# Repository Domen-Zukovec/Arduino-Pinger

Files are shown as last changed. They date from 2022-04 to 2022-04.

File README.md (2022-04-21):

# Arduino pinger
----------------
## Outside
- four buttons
- Red and green LEDs
- LCD display


## Inside
- shield for soldering
- ethernet shield
- Arduino mega 2560


## Functions
- Ping
- Checking the connection, does it work or not
- Detect whether the cable is connected
- Network detection (internet or voice / video)

## Pinging
- Local
- Google
- Voice
- Video


## One time ping
- OK


- ERROR



## Ping till cancel
- OK


- ERROR



## Circuits


## Extra info
- The program has 2002 lines of code in the C ++ programming language
- In addition to the loop and setup, there are 9 other functions
- It has 105 if conditions
- We use the while loop 38 times

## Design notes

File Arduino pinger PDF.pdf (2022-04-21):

# Arduino pinger

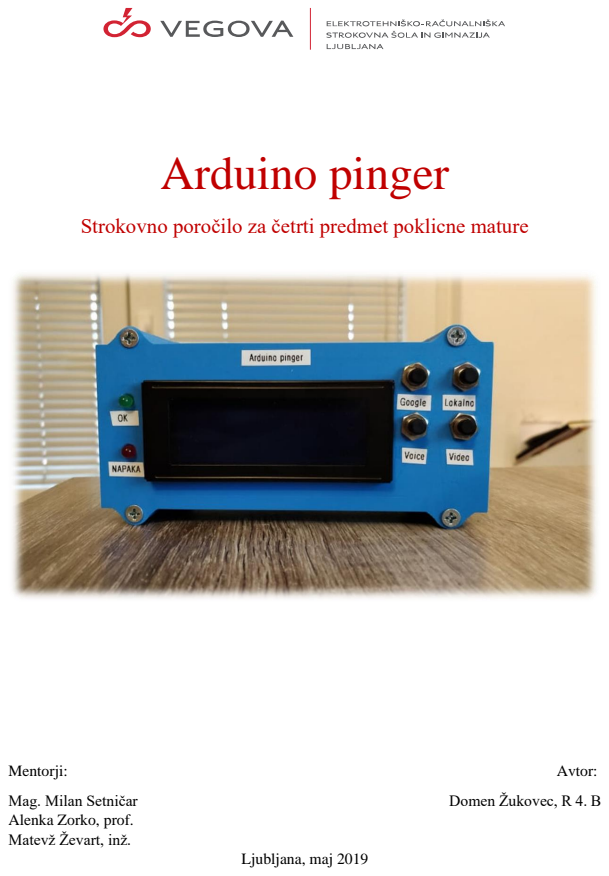
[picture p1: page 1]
Mentorji:; Avtor:; Mag. Milan Setničar; Domen Žukovec, R 4. B; Ljubljana, maj 2019

Strokovno poročilo za četrti predmet poklicne mature

Alenka Zorko, prof.
Matevž Ževart, inž.

### Povzetek

V poročilu je predstavljen tester omrežij Arduino pinger. Na začetku so opisana računalniška omrežja, natančneje osebna in javna. Nato pa so predstavljena orodja in okolja, ki sem jih uporabljal za izdelavo testerja. Sledi podrobna predstavitev delovanja in sestave Arduino pingerja, za tem pa še težave, s katerimi sem se soočil pri izdelavi.

Ključne besede: Arduino, Arduino pinger, usmerjevalnik, testiranje omrežja

### Abstract

In this report a network tester named is presented. First, we talk about computer networks, specifically public and home networks. Then tools and environments that I used for the creation of the tester are introduced. That follows with a detailed presentation on how the Arduino pinger works and how it's made. Next we talk about some problems I had to work around and in the end I present a conclusion.

Key words: Arduino, Arduino pinger, router, network testing

## Kazalo

## Kazalo slik

# 1.Uvod

Za izdelavo Arduino pingerja sem se odločil, saj za testiranje omrežja z računalnikom tehnik na terenu porabi preveč časa in usmerjevalnik brez kakršnegakoli testiranja velikokrat kar zamenja za novega. Delujoči usmerjevalniki so zato velikokrat brez potrebe poslani na servis, kar podjetjem, sploh večjim kot so Telekom d. d., povzroča velike denarne izgube. Spodbudo za izdelavo naprave mi je dal mentor Matevž Ževart med prakso na Telekomu. Arduino pinger je kompaktna in lahka naprava, ki jo tehnik lahko brez težav nosi po terenu in z njo v sekundah preveri delovanje povezave z usmerjevalnikom, glavnim strežnikom Googla (torej internetom) in s telefonsko ter televizijsko linijo (1).

# 2. Računalniška omrežja

## 2.1 Domače omrežje

Je proces povezovanja vseh naprav v domu skupaj z internetom. Domače omrežje se uporablja za vzpostavitev povezave med napravami, ki jih uporabljamo doma. Podobno je standardnemu omrežju LAN ali WLAN, ki je krajevno omejeno. Predvsem ga uporabljamo za povezovanje potrošnikov in njihovih naprav. Ti vključujejo računalnike, prenosnike, mobilne telefone, tablice in televizorje. Na splošno se domače omrežje lahko doseže s pomočjo usmerjevalnika, ki ga nudi ponudnik internetnih storitev, ki ima lahko podporo za več žičnih ali brezžičnih vrst povezav. Vse naprave se lahko neposredno povežejo z modemom, da lahko dostopajo do interneta (2).

## 2.2 Javno omrežje

Je vrsta omrežja do katerega ima lahko dostop vsakdo in se prek njega lahko poveže z drugimi omrežji ali internetom. To je v nasprotju z zasebnim (domačim) omrežjem, kjer se določijo omejitve in pravila dostopa. Ker ima javno omrežje malo omejitev ali pa jih sploh nima, morajo uporabniki pri dostopanji paziti na morebitna varnostna tveganja. Javno omrežje je označba uporabe in ne topologija ali drugo tehnično povezano načelo. Tehnične razlike med zasebnim in javnim omrežjem glede strojno opremo in infrastrukturo ni, razen varnostnih sistemov ter sistemov za nastavljanje in preverjanje prisotnosti (3).

# 3. Orodja in okolja

## 3.1 Arduino

Arduino je podjetje, ki temelji na odprtokodni strojni in programski opremi. Poleg podjetja je tudi skupnost, kateri lahko prispeva vsak. Glavna funkcija podjetja je oblikovanje in izdelovanje enoploščnih mikrokrmilnikov ter mikrokrmilniških kompletov za izgradnjo digitalnih naprav in interaktivnih objektov. Njihovi izdelki so licencirani v skladu z GNU General Public License (GPL) oziroma z splošno javno licenco, kar omogoča izdelavo Arduino plošč in distribucijo programske opreme z strani vseh. Vezja so komercialno na voljo v že vnaprej sestavljeni obliki ali pa kot kompleti za samo izdelavo.

Modeli plošč uporabljajo vrsto mikroprocesorjev in krmilnikov. Vezja so opremljena z digitalnimi in analognimi vhodi ali izhodi, na katere lahko priklopimo različne razširitvene plošče (ščite) ali pa druga vezja. Nekateri modeli imajo serijske komunikacijske vmesnike, vključno z univerzalnim serijskim vodilom (USB), ki se uporablja tuti za nalaganje programov iz osebnih računalnikov. Mikrokontrolerje običajno sprogramiramo z pomočjo funkcij iz programskih jezikov C in C++. Poleg tradicionalnih orodij za programiranje, projekt Arduino zagotavlja svoje integrirano razvojno okolje (IDE) (4).

## 3.1.1 Zgodovina

Projekt Arduino se je začel leta 2003 kot program za študente na Interactive Design Institute Ivrea v Italiji, s ciljem začetnikom in strokovnjakom zagotoviti poceni in preprost način za ustvarjanje naprav. Primeri takšnih naprav, namenjenih začetnikom, so enostavni roboti, termostati in detektorji gibanja. Ime Arduino izhaja iz bara v Ivrea v Italiji, kjer so se srečali ustanovitelji projekta.

## 3.1.2 Arduino Mega 2560

Mega 2560 je zasnovan za bolj komplekse projekte. Ima 54 digitalnih vhodno/izhodnih zatičev (od tega 15 lahko uporabimo kot PWM-izhode), 16 analognih vhodov, 4 UART(strojna serijska vrata), 16 MHz-kristalni oscilator, USB-povezljivost, vtičnico, ICSP-glavo in gumb za ponastavitev. Vsebuje vse, kar je potrebno za podporo mikrokrmilnika. Plošča Mega 2560 je združljiva z večino ščitov za Uno.

## 3.1.3 Arduinovo integrirano razvojno okolje (IDE)

Je aplikacija za Windows, MacOS, Linux, ki je napisana v programskem jeziku Java. Izvira iz integriranega razvojnega okolja za programska jezika Processing in Wiring. Vključuje urejevalnik kod s funkcijami, kot so izrezovanje in lepljenje besedila, iskanje in zamenjava besedila, samodejno zamikanje, ujemanje spojev, avtomatsko urejanje kode in poudarjanje sintaks. Omogoča prevajanje in nalaganje skripte na Arduino vezje z enim klikom. Vsebuje tudi območje za sporočila, besedilno konzolo, orodno vrstico gumbi za skupne funkcije in hierarhijo menijev.

Arduino IDE podpira jetike C in C++ s posebnimi pravili strukturiranja kode. Programsko knjižnico dobavlja iz projekta Wiring, ki ponuja številčne skupne vhodne in izhodne postopke. Uporabniško napisana koda zahteva samo dve osnovni funkciji, za zagon skice in glavne programske zanke, ki sta main() in loop(). Arduino IDE uporablja program Avrdude za pretvorbo izvršljive kode v besedilno datoteko v šestnajstiškem kodiranju, ki se naloži na Arduino ploščo s programom za nalaganje.

3.2 C++

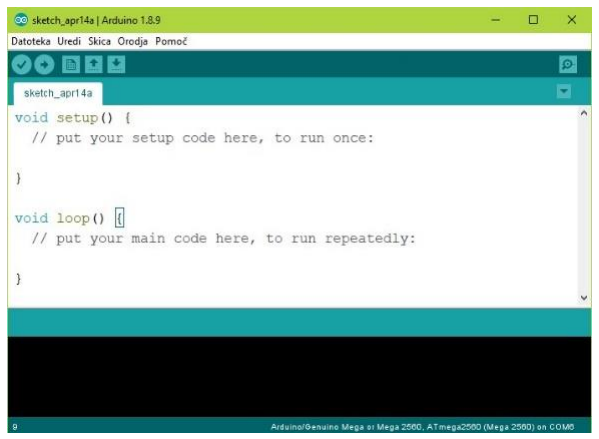
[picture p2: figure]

Programski jezik C++ je izboljšana verzija jezika C, ki se običajno uporablja za objektno usmerjeno programiranje. Razvija se že več kot trideset let. Čeprav je to daleč od najstarejšega računalniškega jezika, je to eden starejših, ki je danes v splošni rabi. Zato lahko rečemo da je dobil petko ta sposobnost prilagajanja spreminjajočim se tehnološkim časom.

C++ je razvil Bjarne Strostrup, ki je opravil prvi prototip kot del svojega doktorskega projekta. V zgodnjih letih se je imenoval jezik »C z razredi«. Začel je razvijati nov jezik, ker je menil, da noben obstoječ ni bil idealen za velike projekte. Kasneje, ko je delal v AT&T Bell Labs, se je spet počutil omejeno. Zavrgel je svoj »C z razredi« in upeljal še druge jezike. Na koncu je poleg razredov dodal še virtualne funkcije, predloge (templates) in preobremenitev operatorja (operator overloading).

Slika 1: Arduinovo IDE-okolje

C++ je precej presegel delo enega človeka. Ime se je dejansko spomnil drug razvijalec Rick Mascitti. Delno je bila igra besed na ime operaterja »++« in delno sklicevanje na izboljšavo (dva plusa sta morda tudi šala).

Jezik je bil prvič standardiziran leta 1998. Standardi si bili ponovno obnovljeni leta 2003, 2007 in 2011. Jezik C++ zdaj vzdržuje International Organization for Standardization (ISO), ki je velika organizacija za standarde. Trenutna različica programskega jezika je C++20. Glavni cilji za zdaj so, da postane boljši jezik za vgrajene sisteme in da bolje podpira novince.

C++ se pogosto uporablja v programskem inženirstvu vgrajenih sistemov. Priljubljen je tudi v komunikacijskih aplikacijah in igrah. Uporablja se v mnogih različnih panogah, kot so zdravstvo, finance…Eden od razlogov, da se programerji odločijo za C++, je, da se dobro povezuje z drugimi programskimi jeziki. Še en plus je njegova visoka zmogljivost. C++ je vplival tudi na kasnejše jezike, kot so PHP, Java, C#... (5)

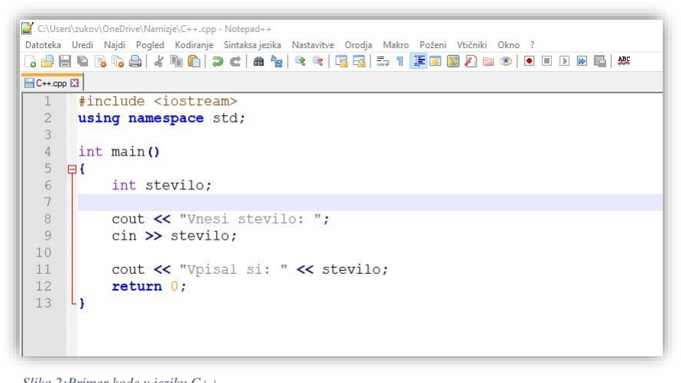
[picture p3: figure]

## 3.3Notepad++

Notepad++ je brezplačen urejevalnik izvorne kode in nadomestek za beležnico, ki podpira veliko več programskih jezikov. Temelji na zmogljivi komponenti za urejanje Scintilla, napisan je v jeziku C++ in uporablja Win32 API in STL, ki zagotavlja višjo hitrost izvajanja in manjšo velikost programa. Z dobro optimizacijo poskuša Notepad++ uporabniku ponuditi najboljšo možno storitev z minimalno procesorsko močjo (6).

Slika 2:Primer kode v jeziku C++

## 3.4 3D-tiskanje

## 3.4.1 Delovanje 3D-tiskanja

Vsak 3D-tiskalnik deluje na isti glavni princip. Digitalni model se spremeni v fizični tridimenzionalni objekt z dodajanjem materiala (plastike) plast na plast. 3D-tiskanje je bistveno drugačen način izdelave delov v primerjavi s tradicionalnimi tehnologijami izrezovanja (CNC obdelava) ali proizvodnimi tehnologijami (injection molding). Pri 3D tiskanju niso potrebna posebna orodja (npr. rezalno orodje z določeno geometrijo ali kalup). Namesto tega je izdelan neposredno na vgrajeno platformo, po slojih, kar vodi do edinstvenih nizov prednosti in omejitev.

Proces se vedno začne z digitalnim 3D-modelom (načrtom fizičnega objekta). Model s programsko opremo tiskalnika razdelimo v tanke, dvodimenzionalne plasti, ki jih nato pretvori v niz navodil, da jih lahko tiskalnik tiska.

3D-tiskanje se lahko razlikuje odvisno od procesa, s katerim tiskamo. Na primer, namizni računalniki raztapljajo plastične filamente in jih položijo na tiskalno platformo skozi šobo. Veliki industrijski SLS stroji pa uporabljajo laser za taljenje (ali sintranje) tankih plasti kovinskih ali plastičnih prahov. Razpoložljivi materiali se razlikujejo tudi glede na proces. Plastika je daleč najpogostejša, uporabljamo pa lahko tudi kovino. Proizvedeni deli imajo lahko tudi širok spekter specifičnih lastnosti, od optično čistih, do gumastih predmetov. Odvisno od velikosti dela in vrste tiskalnika lahko traja tiskanje od štiri do osemnajst ur. Tiskani deli pa so redko pripravljeni za uporabo takoj po tisku. Velikokrat zahtevajo še nekaj naknadne obdelave, da se doseže želena raven kvalitete. Ti koraki zahtevajo dodaten čas in običajno ročen napor (7).

## 3.4.2 Zgodovina 3D-tiskalnikov

Arthur C. Clarke je prvič opisal osnovne funkcije 3D-tiskalnika leta 1964. Prvi 3D tiskalnik je leta 1987 izdelal Chuck Hull, uporabljal pa je sistem »stereolitografije«. V devetdesetih in dva tisočih so bile izdelane druge tehnologije 3D-tiskanja (FDM in SLS). Ti tiskalniki so bili dragi in se v glavnem uporabljajo za industrijsko izdelavo prototipov. Odbor za ASTM F42 je leta 2009 objavil dokument s standardno terminologijo o aditivni proizvodnji. To je vzpostavilo 3D tiskanje kot industrijsko proizvodnjo tehnologijo. V istem letu so se patenti za FDM iztekli in prvi poceni 3D namizni tiskalniki so začeli nastajati pod okvirjem projekta RepRap. Kar je nekoč stalo 200.000€, je nenadoma postalo dostopno za manj kot 2.000€. V obdobju 2015-2017 je bilo globalno prodanih več kot 1 milijon 3D-tiskalnikov, prodaja industrijskih kovinskih tiskalnikov pa se je leta 2017 v primerjavi s prejšnjim letom skoraj podvojila.

## 3.4.3 Tinkercad

Ustanovljen je bil leta 2011. Je največja skupnost 3D-oblikovalcev in navdušencev 3D-tiskanja. Do zdaj je privabil več kot sedem milijonov uporabnikov, vsako minuto pa se pridružijo novi. Aktivna skupnost je skupaj ustvarila že več kot petdeset milijonov 3D modelov, vsak dan pa je dodanih še na tisoče novih. Konec leta 2016 je prvotni Tinkercad urednik predstavil popolnoma prenovljen urejevalnik v2.0, ki deluje 800 % hitreje kot prej in nam omogoča, da povečavo aplikacije na načine, ki jih stari ne more. Junija 2013 je Tinkercad postal del družine aplikacij Autodeska (8).

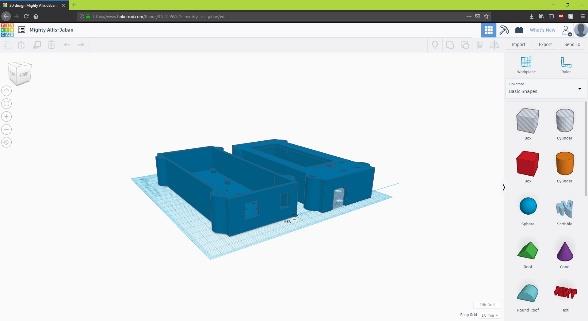
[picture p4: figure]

# 4. Delovanje

## 4.1 Program in funkcije

Program je napisan v Arduinovem IDE-okolju. Glavne funkcije so enkraten ali konstanten ping lokalnega usmerjevalnika, Googlovega strežnika, telefonske ali video mreže Telekoma Slovenije. Rezultat se izpiše na LCD-zaslonu, za hitrejše razumevanje pa besedilo na zaslonu podpirata se ustrezno prižgani rdeča ali zelena dioda.

Slika 3: Ohišje Arduino pingerja v programu Tinkercad

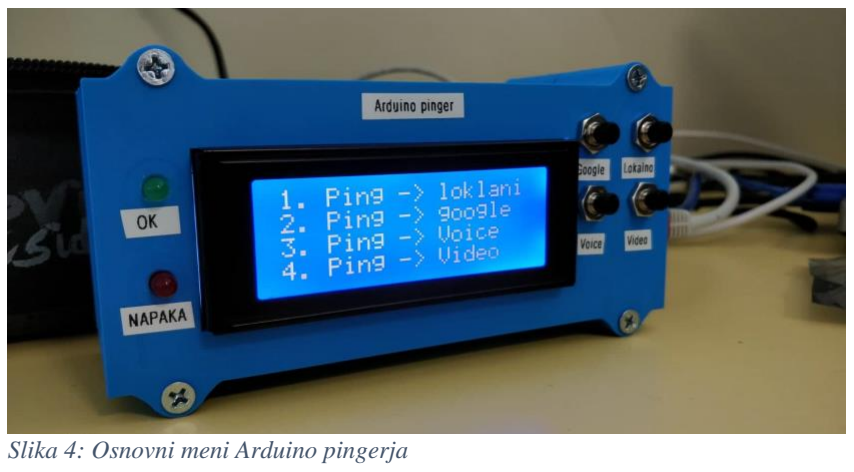
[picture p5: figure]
Slika 4: Osnovni meni Arduino pingerja

## 4.1.1 Osnovne deklaracije

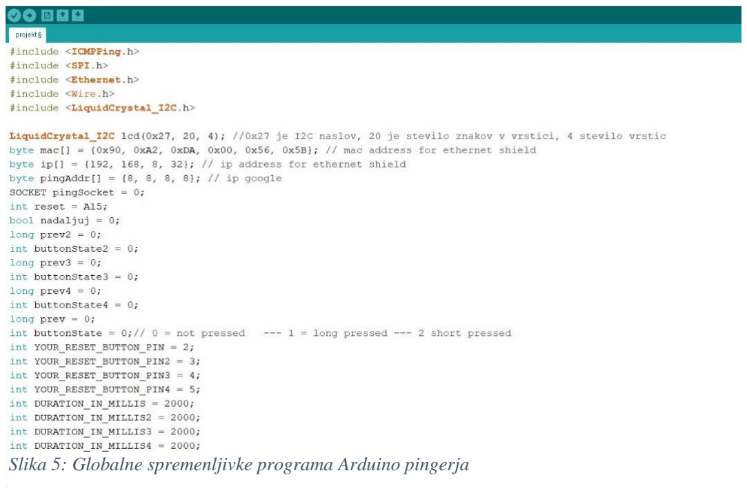
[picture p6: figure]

Izven vseh funkcij se deklarirajo globalne spremenljivke, ki se bodo uporabljale v več kot eni funkciji. Z #include pa se navežemo na knjižnice, ki jih Arduinov IDE v osnovi še nima vključenih. Navezati sem se moral na knjižnice za delovanje internetnega ščita in LCD-zaslona.

## 4.1.2 Funkcija rebootEthShield

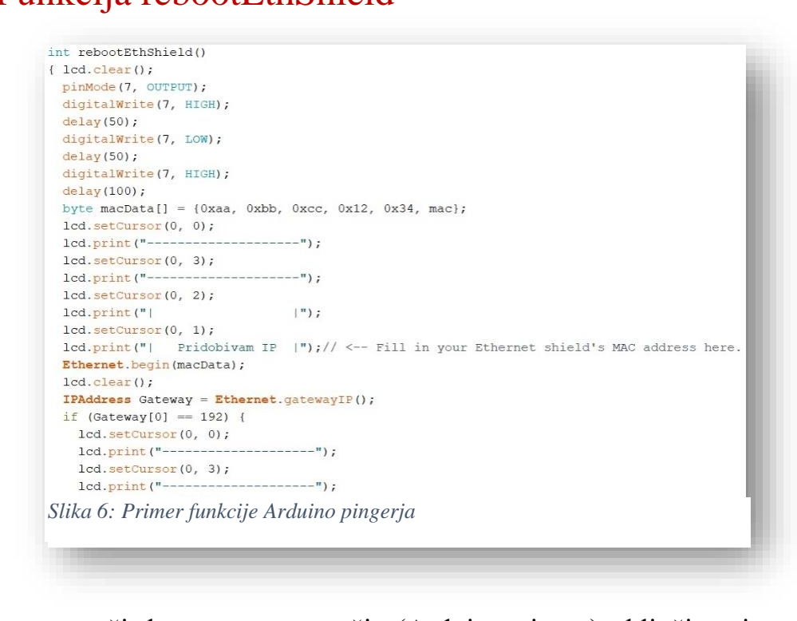
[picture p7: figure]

Funkcija se sproži, ko v tester omrežja (Arduino pinger) vključimo internetni kabel. V funkciji resetiramo internetni ščit (ethernet shield), da dobi nov logični naslov (IP) s katerim bo lahko dostopal na internet oziroma glasovni ali pa video strežnik Telekoma Slovenije.

Slika 5: Globalne spremenljivke programa Arduino pingerja

Slika 6: Primer funkcije Arduino pingerja

## 4.1.3 Funkcije googleKratek

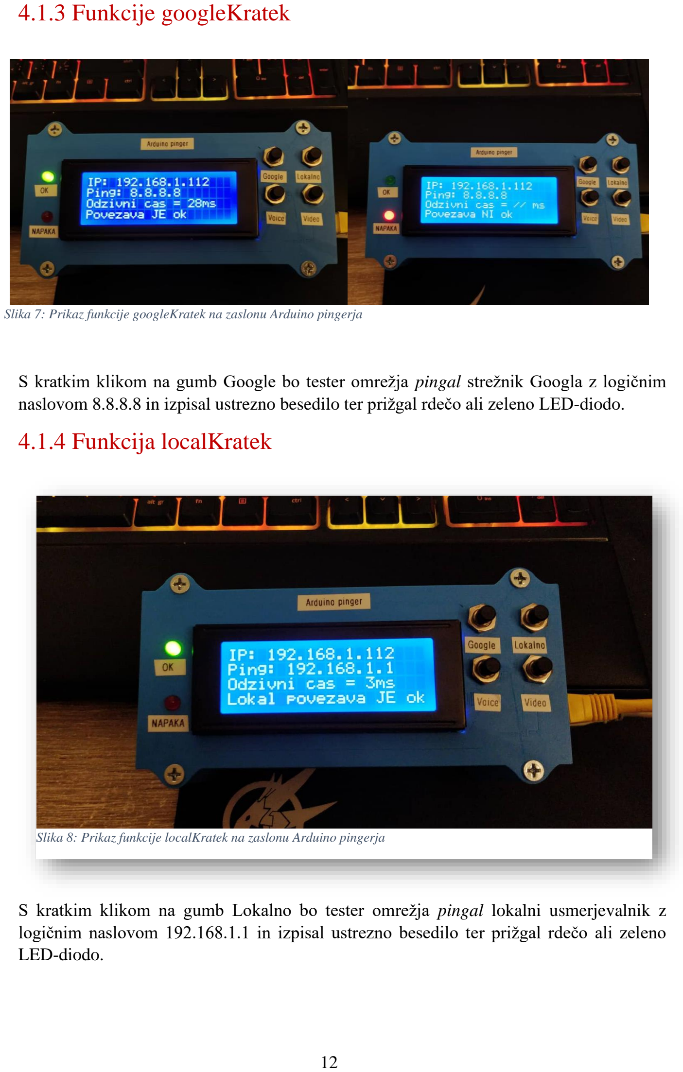
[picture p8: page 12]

S kratkim klikom na gumb Google bo tester omrežja pingal strežnik Googla z logičnim naslovom 8.8.8.8 in izpisal ustrezno besedilo ter prižgal rdečo ali zeleno LED-diodo.

## 4.1.4 Funkcija localKratek

S kratkim klikom na gumb Lokalno bo tester omrežja pingal lokalni usmerjevalnik z logičnim naslovom 192.168.1.1 in izpisal ustrezno besedilo ter prižgal rdečo ali zeleno LED-diodo.

Slika 7: Prikaz funkcije googleKratek na zaslonu Arduino pingerja

Slika 8: Prikaz funkcije localKratek na zaslonu Arduino pingerja

## 4.1.5 Funkcija videoKratek

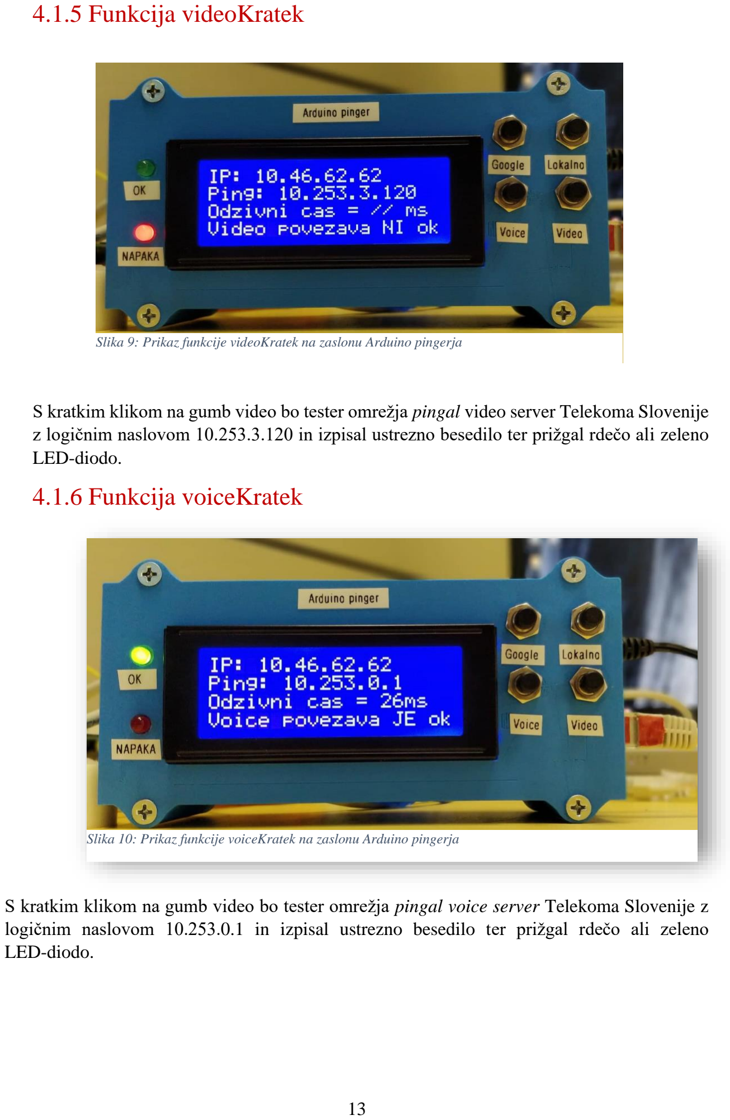
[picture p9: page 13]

S kratkim klikom na gumb video bo tester omrežja pingal video server Telekoma Slovenije z logičnim naslovom 10.253.3.120 in izpisal ustrezno besedilo ter prižgal rdečo ali zeleno LED-diodo.

## 4.1.6 Funkcija voiceKratek

S kratkim klikom na gumb video bo tester omrežja pingal voice server Telekoma Slovenije z logičnim naslovom 10.253.0.1 in izpisal ustrezno besedilo ter prižgal rdečo ali zeleno LED-diodo.

Slika 9: Prikaz funkcije videoKratek na zaslonu Arduino pingerja

Slika 10: Prikaz funkcije voiceKratek na zaslonu Arduino pingerja

## 4.1.7 Funkcija googleDolgi

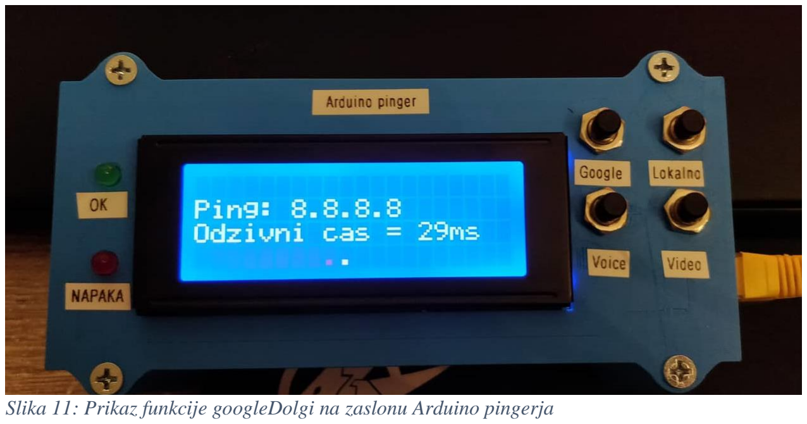
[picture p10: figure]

Z dolgim pritiskom na gumb Google (vsaj dve sekundi) bo tester omrežja začel konstantno pingati strežnik Googla z logičnim naslovom 8.8.8.8, dokler gumba spet ne pridržimo za vsaj dve sekundi. Med pinganjem izpisuje IP, ki ga pingamo, odzivni čas ter indikator s pomočjo katerega lahko izvemo, da pinganje še poteka. V primeru napake v povezavi na LCD-zaslon izpiše »…Ping neuspesen…«

## 4.1.8 Funkcija localDolgi

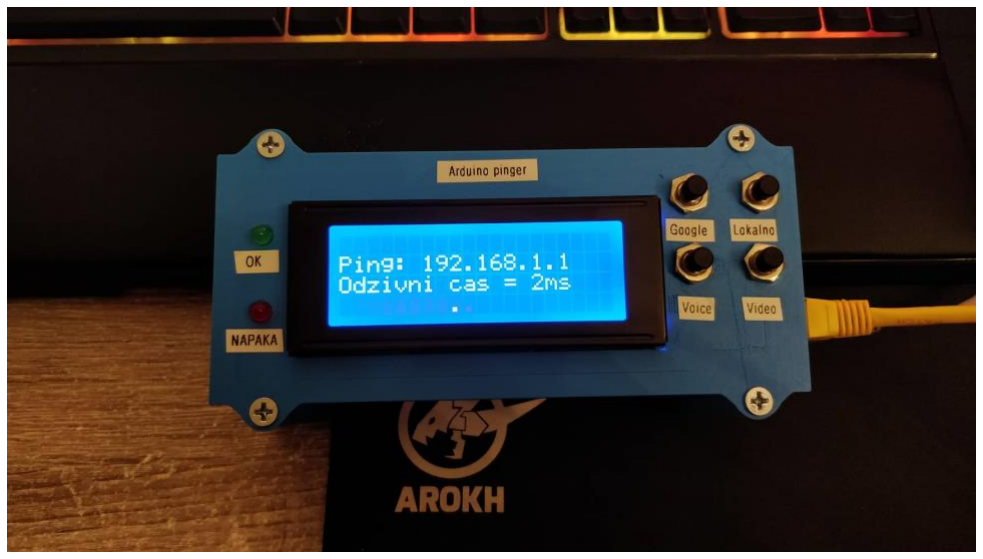
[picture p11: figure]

Z dolgim pritiskom na gumb Lokalno (vsaj dve sekundi) bo tester omrežja začel konstantno pingati lokalni usmerjevalnik z logičnim naslovom 192.167.1.1, dokler gumba spet ne pridržimo za vsaj dve sekundi. Med pinganjem izpisuje IP, ki ga pingamo, odzivni čas ter indikator s pomočjo katerega lahko izvemo, da pinganje še poteka. V primeru napake v povezavi na LCD-zaslon izpiše »…Ping neuspesen…«

Slika 11: Prikaz funkcije googleDolgi na zaslonu Arduino pingerja

Slika 12: Prikaz funkcije localDolgi na zaslonu Arduino pingerja

## 4.1.9 Funkcija videoDolg

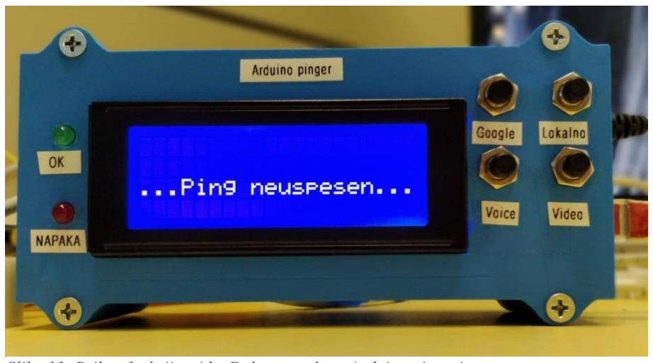
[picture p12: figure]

Z dolgim pritiskom na gumb Video (vsaj dve sekundi) bo tester omrežja začel konstantno pingati video strežnik Telekoma Slovenije z logičnim naslovom 10.253.3.120, dokler gumba spet ne pridržimo za vsaj dve sekundi. Med pinganjem izpisuje IP, ki ga pingamo, odzivni čas ter indikator s pomočjo katerega lahko izvemo, da pinganje še poteka. V primeru napake v povezavi na LCD-zaslon izpiše »…Ping neuspesen…«

## 4.1.10 Funkcija voiceDolg

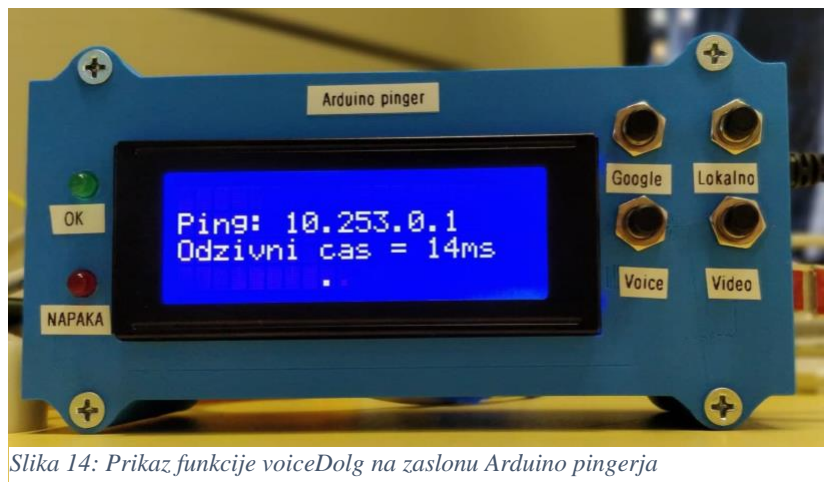
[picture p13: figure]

Z dolgim pritiskom na gumb Video (vsaj dve sekundi) bo tester omrežja začel konstantno pingati voice strežnik Telekoma Slovenije z logičnim naslovom 10.253.0.1, dokler gumba spet ne pridržimo za vsaj dve sekundi. Med pinganjem izpisuje IP, ki ga pingamo, odzivni čas ter indikator s pomočjo katerega lahko izvemo, da pinganje še poteka. V primeru napake v povezavi na LCD-zaslon izpiše »…Ping neuspesen…«

Slika 13: Prikaz funkcije videoDolg na zaslonu Arduino pingerja

Slika 14: Prikaz funkcije voiceDolg na zaslonu Arduino pingerja

## 4.1.11 Funkciji loop in setup

V funkciji loop čakamo na klik gumba in posredno kličemo ustrezno funkcijo. V setupu pa deklariramo spremenljivke in kličemo vse kar potrebujemo za delovanje ostalih funkcij.

## 4.1.12 Preverjanje funkcij gumba

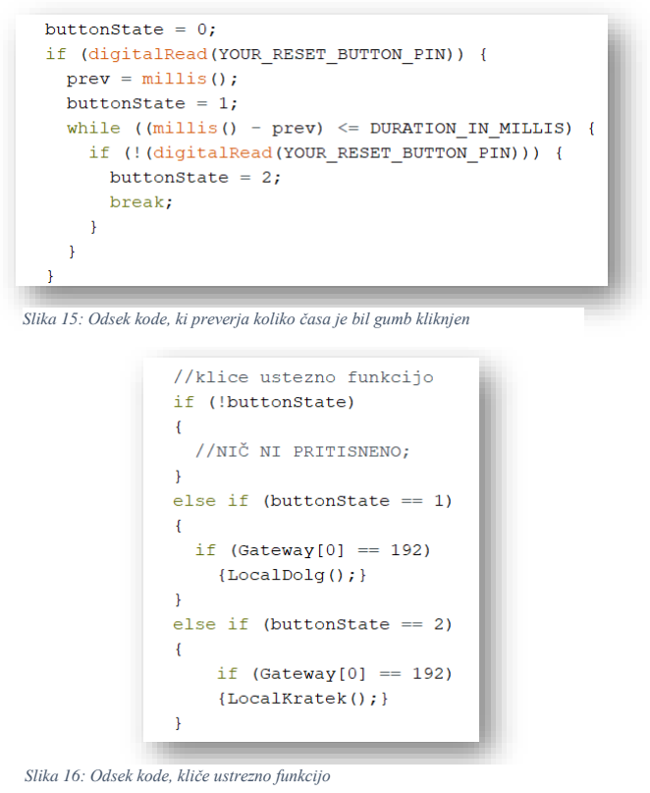
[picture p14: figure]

Na prvi sliki je prikazana koda, s pomočjo katere preverjamo, koliko časa je določen gumb pridržan. To dosežemo z uporabo funkcije millis(). Na drugi sliki pa lahko vidimo, kako se po izvedbi kode iz prve slike izvede if-stavek s katerim se kliče ustrezna funkcija.

Slika 16: Odsek kode, kliče ustrezno funkcijo

Slika 15: Odsek kode, ki preverja koliko časa je bil gumb kliknjen

## 4.2 Sestavni deli

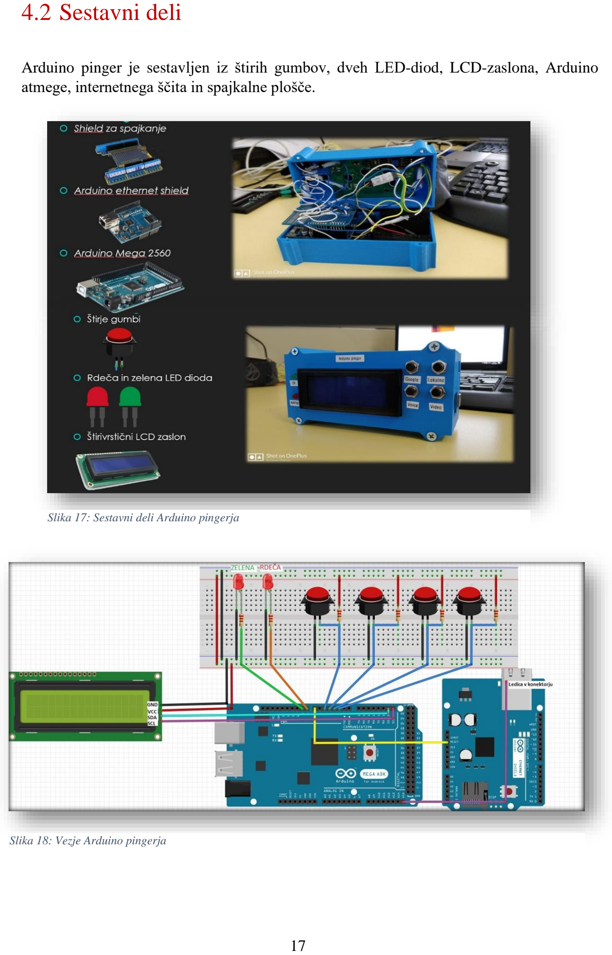
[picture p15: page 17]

Arduino pinger je sestavljen iz štirih gumbov, dveh LED-diod, LCD-zaslona, Arduino atmege, internetnega ščita in spajkalne plošče.

Slika 17: Sestavni deli Arduino pingerja

Slika 18: Vezje Arduino pingerja

# 5.Težave pri razvoju

Pri razvoju sem naletel na le nekaj večjih težav. Prva od teh je bila, da sem imel starejšo različico internetnega ščita, ki ni podpirala ponastavitve preko programske kode, kar pomeni, da sem moral nogico za resetiranje zakriviti, tako da se ni usedla na Arduino, ampak je bila prosta. Nato sem nanjo spajkal kabel, kisem ga vključil v prost vtič Arduinota. Če bi nogico pustil na prvotnem mestu, bi se namreč ščit ponastavil samo skupaj z Arduinom, tako pa sem imel popolno kontrolo nad ponastavitvijo. Drugo večjo težavo pa so mi povzročali gumbi, saj nisem imel dovolj znanja, da bi z enim gumbom zagotovil izvajanje dveh funkcij. S težavo sem se spopadal en teden, preden sem dobil zadovoljivo rešitev. Med izdelavo sem naletel še na obilico majhnih težav, ki sem jih skupaj z mentorjem hitro odpravil.

# 6. Zaključek

Kljub možnostim izboljšave sem z Arduino pingerjem zadovoljen. Lahko bi dodal še številčnico za poljubno vpisovanje logičnih naslovov, a bi bila taka naprava mogoče za nekatere preveč zapletena za uporabo. Namen projekta je bil, da sestavim tester omrežij, ki je preprost za uporabo, a vseeno dovolj zmogljiv, da lahko tehnikom na terenu pomaga pri iskanju napak ali rešitev. Poskušal sem ga narediti čimbolj uporabniku prijaznega in zdi se mi, da mi je to tudi uspelo. Nima odvečnih animacij, uporaba je preprosta in prikaz je lahko razumljiv. V prihodnosti bi rad dodal še notranjo baterijo in izboljšal ohišje oziroma ga poskušal narediti tanjšega.

# 7. Viri in literatura

Vsi internetni viri so bili dosegljivi aprila 2019.

(1) http://wiki.fmf.uni-lj.si/wiki/Vrste_omre%C5%BEja
(2) https://www.techopedia.com/definition/23525/home-networking
(3) https://www.techopedia.com/definition/26424/public-network
(4) https://www.arduino.cc/
(5) https://www.softwareengineerinsider.com/programming-languages/cplusplus.htm
(6) https://notepad-plus-plus.org/
(7) https://www.3dhubs.com/guides/3d-printing/#basics
(8) https://www.tinkercad.com/about/

## 7.1 Viri slik

- Slika na naslovnici: lastna slika, zajeta aprila 2019
- Slike 1–16: lastne slike, zajete aprila 2019

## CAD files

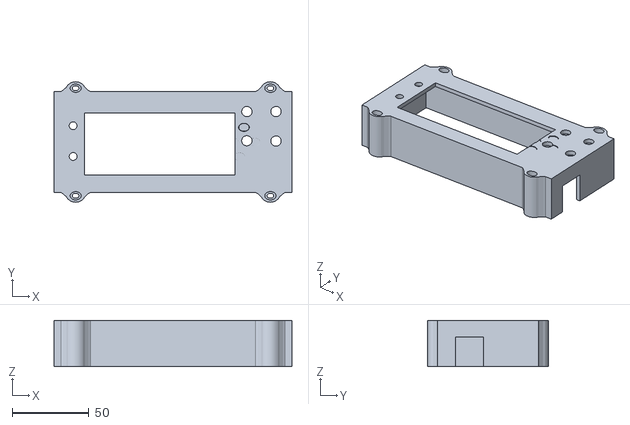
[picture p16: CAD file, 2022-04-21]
Arduino pinger projet/Pinger tinkercad 3D print/Arduino pinger zgornji del popravljen.obj
155.0 x 78.5 x 30.0

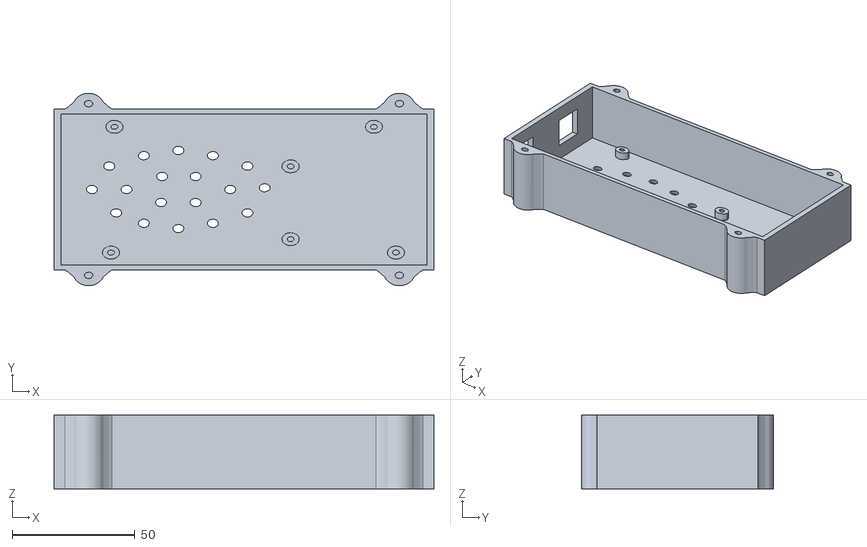
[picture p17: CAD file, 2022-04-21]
Arduino pinger projet/Pinger tinkercad 3D print/Arduino_Pinger_spodnji_del.stl
155.0 x 78.5 x 30.0

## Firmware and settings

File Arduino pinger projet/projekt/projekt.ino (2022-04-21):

#include <ICMPPing.h>
#include <SPI.h>
#include <Ethernet.h>
#include <Wire.h>
#include <LiquidCrystal_I2C.h>


//Primer vseh funkcij za LCD zaslon:
/*###########################################
  # Methods and Functions (KEYWORD2)
  ###########################################
  init  KEYWORD2
  begin KEYWORD2
  clear KEYWORD2
  home  KEYWORD2
  noDisplay KEYWORD2
  display KEYWORD2
  noBlink KEYWORD2
  blink KEYWORD2
  noCursor  KEYWORD2
  cursor  KEYWORD2
  scrollDisplayLeft KEYWORD2
  scrollDisplayRight  KEYWORD2
  leftToRight KEYWORD2
  rightToLeft KEYWORD2
  shiftIncrement  KEYWORD2
  shiftDecrement  KEYWORD2
  noBacklight KEYWORD2
  backlight KEYWORD2
  autoscroll  KEYWORD2
  noAutoscroll  KEYWORD2
  setCursor KEYWORD2
  print KEYWORD2
  blink_on  KEYWORD2
  blink_off KEYWORD2
  cursor_on KEYWORD2
  cursor_off  KEYWORD2
  load_custom_character KEYWORD2
  printstr  KEYWORD2
*/

LiquidCrystal_I2C lcd(0x27, 20, 4); //0x27 je I2C naslov, 20 je stevilo znakov v vrstici, 4 stevilo vrstic

byte mac[] = {0x90, 0xA2, 0xDA, 0x00, 0x56, 0x5B}; // mac address for ethernet shield
byte ip[] = {192, 168, 8, 32}; // ip address for ethernet shield
byte pingAddr[] = {8, 8, 8, 8}; // ip google


SOCKET pingSocket = 0;


int reset = A15;
bool nadaljuj = 0;
long prev2 = 0;
int buttonState2 = 0;
long prev3 = 0;
int buttonState3 = 0;
long prev4 = 0;
int buttonState4 = 0;
long prev = 0;
int buttonState = 0;// 0 = not pressed   --- 1 = long pressed --- 2 short pressed
int YOUR_RESET_BUTTON_PIN = 2;
int YOUR_RESET_BUTTON_PIN2 = 3;
int YOUR_RESET_BUTTON_PIN3 = 4;
int YOUR_RESET_BUTTON_PIN4 = 5;
int DURATION_IN_MILLIS = 2000;
int DURATION_IN_MILLIS2 = 2000;
int DURATION_IN_MILLIS3 = 2000;
int DURATION_IN_MILLIS4 = 2000;
int google_pritisk = 200;

int delayMS = 4 * 1000; // delay between successive pings (60 * 1000 = 60 seconds)







int rebootEthShield()
{ lcd.clear();

  //  Serial.println("Rebooting ethernet shield...");
  pinMode(7, OUTPUT);

  digitalWrite(7, HIGH);

  delay(50);

  digitalWrite(7, LOW);

  delay(50);

  digitalWrite(7, HIGH);

  delay(100);

  

  byte macData[] = {0xaa, 0xbb, 0xcc, 0x12, 0x34, mac};
  lcd.setCursor(0, 0);
  lcd.print("--------------------");
  lcd.setCursor(0, 3);
  lcd.print("--------------------");
  lcd.setCursor(0, 2);
  lcd.print("|                  |");
  lcd.setCursor(0, 1);
  lcd.print("|   Pridobivam IP  |");// <-- Fill in your Ethernet shield's MAC address here.
  Ethernet.begin(macData);

  // delay(500);
  // client.setTimeout(500);
  //  wdt_reset(); //resetiram watchdog timer
  lcd.clear();
IPAddress Gateway = Ethernet.gatewayIP();
  if (Gateway[0] == 192){
      
   
  lcd.setCursor(0, 0);
  lcd.print("--------------------");
  lcd.setCursor(0, 3);
  lcd.print("--------------------");
  lcd.setCursor(0, 2);
  lcd.print("|                  |");
  lcd.setCursor(0, 1);
  lcd.print("|     Internet     |");
  delay(2000);

    
  }else{ 
    
   lcd.setCursor(0, 0);
  lcd.print("--------------------");
  lcd.setCursor(0, 3);
  lcd.print("--------------------");
  lcd.setCursor(0, 2);
  lcd.print("|                  |");
  lcd.setCursor(0, 1);
  lcd.print("|    Voice/Video   |");
  delay(2000);}
}




void googleKratek() {
  char buffer [256];
  int TTL = 0;
  int ping_time = 0;


  int sensorVal = digitalRead(2);
  int sensorVal2 = digitalRead(3);
  int naprej1 = digitalRead(2);
  int naprej2 = digitalRead(3);
  int neki = digitalRead(4);
  bool ja = 0;
  bool ja2 = 0;
  bool ne = 0;
  bool ne2 = 0;
  lcd.clear();

  //KRATKI!


  Serial.println("TODO button is pressed ");
  IPAddress Lokalni_ip = Ethernet.localIP();
  IPAddress Gateway = Ethernet.gatewayIP();



  Serial.println(Lokalni_ip[1]);
  //byte pingAddr[] = {Gateway[0],Gateway[1],Gateway[2],Gateway[3]};

  bool pingRet; // pingRet stores the ping() success (true/false)
  //startPing();
  ICMPPing ping(pingSocket);
  pingRet = ping(4, pingAddr, buffer, &ping_time, &TTL);
  delay(250);
  //endPing();


  Serial.println(buffer);
  //lcd.print(buffer);




  if (pingRet && ping_time < 2000 && ping_time >= 0 ) // Failure
  { digitalWrite(9, HIGH);
    // pingSuccess();
  //  neki = LOW; //tezava z gumbi moral restit programsko, saj je gumb vezan na pulup in ne dobi dost hitr low in se loop sploh ne zacne
    while (neki == LOW && ja == 0) {
      neki = digitalRead(3);
      lcd.setCursor(0, 0);
      lcd.print("IP: " );
      lcd.print(Lokalni_ip);
      lcd.setCursor(0, 1);
      sprintf(buffer, "Ping: %d.%d.%d.%d", pingAddr[0], pingAddr[1], pingAddr[2], pingAddr[3]);
      Serial.println(buffer);
      lcd.print(buffer);

      lcd.setCursor(0, 2);
      lcd.print("Odzivni cas = ");
      lcd.print(ping_time);
      lcd.print("ms");

      lcd.setCursor(0, 3);
      lcd.print("Povezava JE ok");

      reset = analogRead(A15);
      //Serial.println(reset);
      if (reset < 380 || reset > 460) {
        lcd.clear();
        lcd.setCursor(0, 0);
        lcd.print("--------------------");
        lcd.setCursor(0, 1);
        lcd.print("|Kabel ni vkljucen |");
        lcd.setCursor(0, 3);
        lcd.print("--------------------");
        int lala = 0;
        while (reset < 380 || reset > 460) {
          lcd.setCursor(0, 2);
          lcd.print("|    Vkljuci ga!   |");
          reset = analogRead(A15);
        }
        if (reset > 380 && reset < 460 && lala == 0)
        {
          lala++;
          rebootEthShield();
          ja = 1;


        }
      }
    }
    digitalWrite(9, LOW);
    lcd.clear();
    lcd.setCursor(1, 0);
    lcd.print("1. Ping -> loklani");
    lcd.setCursor(1, 1);
    lcd.print("2. Ping -> google");
    lcd.setCursor(1, 2);
    lcd.print("3. Ping -> Voice");
    lcd.setCursor(1, 3);
    lcd.print("4. Ping -> Video");
    delay(100);
  }
  else
  { digitalWrite(8, HIGH);
    //pingFail();
    lcd.setCursor(0, 0);
    lcd.print("IP: " );
    lcd.print(Lokalni_ip);
    lcd.setCursor(0, 1);
    sprintf(buffer, "Ping: %d.%d.%d.%d", pingAddr[0], pingAddr[1], pingAddr[2], pingAddr[3]);
    Serial.println(buffer);
    lcd.print(buffer);
  //  neki = LOW; //tezava z gumbi moral restit programsko, saj je gumb vezan na pulup in ne dobi dost hitr low in se loop sploh ne zacne
    while (neki == LOW && ja2 == 0) {
      neki = digitalRead(3);
      lcd.setCursor(0, 2);
      lcd.print("Odzivni cas = // ");
      //lcd.print(ping_time);
      lcd.print("ms");

      lcd.setCursor(0, 3);
      lcd.print("Povezava NI ok");

      reset = analogRead(A15);
      Serial.println(reset);
      if (reset < 380 || reset > 460) {
        lcd.clear();
        lcd.setCursor(0, 0);
        lcd.print("--------------------");
        lcd.setCursor(0, 1);
        lcd.print("|Kabel ni vkljucen |");
        lcd.setCursor(0, 3);
        lcd.print("--------------------");
        int lala = 0;
        while (reset < 380 || reset > 460) {
          lcd.setCursor(0, 2);
          lcd.print("|    Vkljuci ga!   |");
          reset = analogRead(A15);
        }
        if (reset > 380 && reset < 460 && lala == 0)
        {
          lala++;
          rebootEthShield();
          ja2 = 1;

        }
      }
    }
    digitalWrite(8, LOW);
    lcd.clear();
    lcd.setCursor(1, 0);
    lcd.print("1. Ping -> loklani");
    lcd.setCursor(1, 1);
    lcd.print("2. Ping -> google");
    lcd.setCursor(1, 2);
    lcd.print("3. Ping -> Voice");
    lcd.setCursor(1, 3);
    lcd.print("4. Ping -> Video");
    delay(100);
    //TODO button is pressed short
  }
}


void localKratek() {
  char buffer [256];
  int TTL = 0;
  int ping_time = 0;


  int sensorVal = digitalRead(2);
  int sensorVal2 = digitalRead(3);
  int naprej1 = digitalRead(2);
  int naprej2 = digitalRead(3);
  int neki = digitalRead(4);
  bool ja = 0;
  bool ja2 = 0;
  bool ne = 0;
  bool ne2 = 0;
  lcd.clear();

  //KRATKI!


  Serial.println("TODO button is pressed ");
  IPAddress Lokalni_ip = Ethernet.localIP();
  IPAddress Gateway = Ethernet.gatewayIP();



  Serial.println(Lokalni_ip[1]);
  byte pingAddr[] = {Gateway[0], Gateway[1], Gateway[2], Gateway[3]};

  bool pingRet; // pingRet stores the ping() success (true/false)
  //startPing();
  ICMPPing ping(pingSocket);
  pingRet = ping(4, pingAddr, buffer, &ping_time, &TTL);
  delay(250);
  //endPing();


  Serial.println(buffer);
  //lcd.print(buffer);




  if (pingRet && ping_time < 2000 && ping_time >= 0 ) // Failure
  { digitalWrite(9, HIGH);
    // pingSuccess();
    neki = LOW; //tezava z gumbi moral restit programsko, saj je gumb vezan na pulup in ne dobi dost hitr low in se loop sploh ne zacne
    while (neki == LOW && ja == 0) {
      neki = digitalRead(2);
      lcd.setCursor(0, 0);
      lcd.print("IP: " );
      lcd.print(Lokalni_ip);
      lcd.setCursor(0, 1);
      sprintf(buffer, "Ping: %d.%d.%d.%d", pingAddr[0], pingAddr[1], pingAddr[2], pingAddr[3]);
      Serial.println(buffer);
      lcd.print(buffer);

      lcd.setCursor(0, 2);
      lcd.print("Odzivni cas = ");
      lcd.print(ping_time);
      lcd.print("ms");

      lcd.setCursor(0, 3);
      lcd.print("Lokal povezava JE ok");

      reset = analogRead(A15);
      Serial.println(reset);
      if (reset < 380 || reset > 460) {
        lcd.clear();
        lcd.setCursor(0, 0);
        lcd.print("--------------------");
        lcd.setCursor(0, 1);
        lcd.print("|Kabel ni vkljucen |");
        lcd.setCursor(0, 3);
        lcd.print("--------------------");
        int lala = 0;
        while (reset < 380 || reset > 460) {
          lcd.setCursor(0, 2);
          lcd.print("|    Vkljuci ga!   |");
          reset = analogRead(A15);
        }
        if (reset > 380 && reset < 460 && lala == 0)
        {
          lala++;
          rebootEthShield();
          ja = 1;


        }
      }
    }
    digitalWrite(9, LOW);
    lcd.clear();
    lcd.setCursor(1, 0);
    lcd.print("1. Ping -> loklani");
    lcd.setCursor(1, 1);
    lcd.print("2. Ping -> google");
    lcd.setCursor(1, 2);
    lcd.print("3. Ping -> Voice");
    lcd.setCursor(1, 3);
    lcd.print("4. Ping -> Video");
    delay(100);
  }
  else
  { digitalWrite(8, HIGH);
    //pingFail();
    lcd.setCursor(0, 0);
    lcd.print("IP: " );
    lcd.print(Lokalni_ip);
    lcd.setCursor(0, 1);
    sprintf(buffer, "Ping: %d.%d.%d.%d", pingAddr[0], pingAddr[1], pingAddr[2], pingAddr[3]);
    Serial.println(buffer);
    lcd.print(buffer);
    neki = LOW; //tezava z gumbi moral restit programsko, saj je gumb vezan na pulup in ne dobi dost hitr low in se loop sploh ne zacne
    while (neki == LOW && ja2 == 0) {
      neki = digitalRead(2);
      lcd.setCursor(0, 2);
      lcd.print("Odzivni cas = // ");
      //lcd.print(ping_time);
      lcd.print("ms");

      lcd.setCursor(0, 3);
      lcd.print("Lokal povezava NI ok");

      reset = analogRead(A15);
      Serial.println(reset);
      if (reset < 380 || reset > 460) {
        lcd.clear();
        lcd.setCursor(0, 0);
        lcd.print("--------------------");
        lcd.setCursor(0, 1);
        lcd.print("|Kabel ni vkljucen |");
        lcd.setCursor(0, 3);
        lcd.print("--------------------");
        int lala = 0;
        while (reset < 380 || reset > 460) {
          lcd.setCursor(0, 2);
          lcd.print("|    Vkljuci ga!   |");
          reset = analogRead(A15);
        }
        if (reset > 380 && reset < 460 && lala == 0)
        {
          lala++;
          lcd.clear();
          rebootEthShield();
          ja2 = 1;

        }
      }
    }
    digitalWrite(8, LOW);
    lcd.clear();
    lcd.setCursor(1, 0);
    lcd.print("1. Ping -> loklani");
    lcd.setCursor(1, 1);
    lcd.print("2. Ping -> google");
    lcd.setCursor(1, 2);
    lcd.print("3. Ping -> Voice");
    lcd.setCursor(1, 3);
    lcd.print("4. Ping -> Video");
    delay(100);
    //TODO button is pressed short
  }
}
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
void loop()
{

  IPAddress Lokalni_ip = Ethernet.localIP();
  IPAddress Gateway = Ethernet.gatewayIP();


  //GLEDA KER GUMB SI KLIKNU
  buttonState = 0;
  if (digitalRead(YOUR_RESET_BUTTON_PIN)) {
    prev = millis();
    buttonState = 1;
    while ((millis() - prev) <= DURATION_IN_MILLIS) {
      if (!(digitalRead(YOUR_RESET_BUTTON_PIN))) {
        buttonState = 2;
        break;
      }
    }
  }
  //GLEDA KER GUMB SI KLIKNU


  //GLEDA KER GUMB SI KLIKNU2
  buttonState2 = 0;
  if (digitalRead(YOUR_RESET_BUTTON_PIN2)) {
    prev2 = millis();
    buttonState2 = 1;
    while ((millis() - prev2) <= DURATION_IN_MILLIS2) {
      if (!(digitalRead(YOUR_RESET_BUTTON_PIN2))) {
        delay(100);
        buttonState2 = 2;
        break;
      }
    }
  }
  //GLEDA KER GUMB SI KLIKNU2


  //GLEDA KER GUMB SI KLIKNU3
  buttonState3 = 0;
  if (digitalRead(YOUR_RESET_BUTTON_PIN3)) {
    prev3 = millis();
    buttonState3 = 1;
    while ((millis() - prev3) <= DURATION_IN_MILLIS3) {
      if (!(digitalRead(YOUR_RESET_BUTTON_PIN3))) {
        buttonState3 = 2;
        break;
      }
    }
  }
  //GLEDA KER GUMB SI KLIKNU3


  //GLEDA KER GUMB SI KLIKNU4
  buttonState4 = 0;
  if (digitalRead(YOUR_RESET_BUTTON_PIN4)) {
    prev4 = millis();
    buttonState4 = 1;
    while ((millis() - prev4) <= DURATION_IN_MILLIS4) {
      if (!(digitalRead(YOUR_RESET_BUTTON_PIN4))) {
        buttonState4 = 2;
        break;
      }
    }
  }
  //GLEDA KER GUMB SI KLIKNU4



  reset = analogRead(A15);
  Serial.println(reset);
  if (reset < 380 || reset > 460) {
    lcd.clear();
    lcd.setCursor(0, 0);
    lcd.print("--------------------");
    lcd.setCursor(0, 1);
    lcd.print("|Kabel ni vkljucen |");
    lcd.setCursor(0, 3);
    lcd.print("--------------------");
    int lala = 0;
    while (reset < 380 || reset > 460) {
      lcd.setCursor(0, 2);
      lcd.print("|    Vkljuci ga!   |");
      Serial.println(reset);
      reset = analogRead(A15);
    }
    if (reset > 380 && reset < 460 && lala == 0)
    {
      lala++;
      rebootEthShield();
      lcd.clear();
      lcd.setCursor(1, 0);
      lcd.print("1. Ping -> loklani");
      lcd.setCursor(1, 1);
      lcd.print("2. Ping -> google");
      lcd.setCursor(1, 2);
      lcd.print("3. Ping -> Voice");
      lcd.setCursor(1, 3);
      lcd.print("4. Ping -> Video");

    }
  }


  //PREVRERJA!
  if (!buttonState)
  {
    //NIČ NI PRITISNENO;
  }
  else if (buttonState == 1)
  {
    if (Gateway[0] == 192) {
      LocalDolg();
      delay(1000);
    }
    else
    { lcd.clear();
      lcd.setCursor(0, 0);
      lcd.print("--------------------");
      lcd.setCursor(0, 3);
      lcd.print("--------------------");
      lcd.setCursor(0, 2);
      lcd.print("|                  |");
      lcd.setCursor(0, 1);
      lcd.print("|  Napacna mreza!  |");
      delay(1500);
      lcd.clear();
      lcd.setCursor(1, 0);
      lcd.print("1. Ping -> loklani");
      lcd.setCursor(1, 1);
      lcd.print("2. Ping -> google");
      lcd.setCursor(1, 2);
      lcd.print("3. Ping -> Voice");
      lcd.setCursor(1, 3);
      lcd.print("4. Ping -> Video");
    }


  }
  else if (buttonState == 2)
  { Serial.println(Gateway[0]);
    if (Gateway[0] == 192)
    {
      localKratek();
    }
    else
    { lcd.clear();
      lcd.setCursor(0, 0);
      lcd.print("--------------------");
      lcd.setCursor(0, 3);
      lcd.print("--------------------");
      lcd.setCursor(0, 2);
      lcd.print("|                  |");
      lcd.setCursor(0, 1);
      lcd.print("|  Napacna mreza!  |");
      delay(1500);
      lcd.clear();
      lcd.setCursor(1, 0);
      lcd.print("1. Ping -> loklani");
      lcd.setCursor(1, 1);
      lcd.print("2. Ping -> google");
      lcd.setCursor(1, 2);
      lcd.print("3. Ping -> Voice");
      lcd.setCursor(1, 3);
      lcd.print("4. Ping -> Video");
    }
  }




  //PREVRERJA2!
  if (!buttonState2)
  {
    //NIČ NI PRITISNENO;
  }
  else if (buttonState2 == 1)
  { if (Gateway[0] == 192) {
      googleDolgi();
      delay(1000);
    }
    else {
      lcd.clear();
      lcd.setCursor(0, 0);
      lcd.print("--------------------");
      lcd.setCursor(0, 3);
      lcd.print("--------------------");
      lcd.setCursor(0, 2);
      lcd.print("|                  |");
      lcd.setCursor(0, 1);
      lcd.print("|  Napacna mreza!  |");
      delay(1500);
      lcd.clear();
      lcd.setCursor(1, 0);
      lcd.print("1. Ping -> loklani");
      lcd.setCursor(1, 1);
      lcd.print("2. Ping -> google");
      lcd.setCursor(1, 2);
      lcd.print("3. Ping -> Voice");
      lcd.setCursor(1, 3);
      lcd.print("4. Ping -> Video");
    }
  }
  else if (buttonState2 == 2)
  {
    if (Gateway[0] == 192) {
      googleKratek();
    }
    else {
      lcd.clear();
      lcd.setCursor(0, 0);
      lcd.print("--------------------");
      lcd.setCursor(0, 3);
      lcd.print("--------------------");
      lcd.setCursor(0, 2);
      lcd.print("|                  |");
      lcd.setCursor(0, 1);
      lcd.print("|  Napacna mreza!  |");
      delay(1500);
      lcd.clear();
      lcd.setCursor(1, 0);
      lcd.print("1. Ping -> loklani");
      lcd.setCursor(1, 1);
      lcd.print("2. Ping -> google");
      lcd.setCursor(1, 2);
      lcd.print("3. Ping -> Voice");
      lcd.setCursor(1, 3);
      lcd.print("4. Ping -> Video");
    }
  }


  //PREVRERJA3!
  if (!buttonState3)
  {
    //NIČ NI PRITISNENO;
  }
  else if (buttonState3 == 1)
  {
    if (Gateway[0] == 10) {
      voiceDolg();
      delay(1000);
    }
    else {
      lcd.clear();
      lcd.setCursor(0, 0);
      lcd.print("--------------------");
      lcd.setCursor(0, 3);
      lcd.print("--------------------");
      lcd.setCursor(0, 2);
      lcd.print("|                  |");
      lcd.setCursor(0, 1);
      lcd.print("|  Napacna mreza!  |");
      delay(1500);
      lcd.clear();
      lcd.setCursor(1, 0);
      lcd.print("1. Ping -> loklani");
      lcd.setCursor(1, 1);
      lcd.print("2. Ping -> google");
      lcd.setCursor(1, 2);
      lcd.print("3. Ping -> Voice");
      lcd.setCursor(1, 3);
      lcd.print("4. Ping -> Video");
    }
  }
  else if (buttonState3 == 2)
  {
    if (Gateway[0] == 10) {
      voiceKratek();
    }
    else {
      lcd.clear();
      lcd.setCursor(0, 0);
      lcd.print("--------------------");
      lcd.setCursor(0, 3);
      lcd.print("--------------------");
      lcd.setCursor(0, 2);
      lcd.print("|                  |");
      lcd.setCursor(0, 1);
      lcd.print("|  Napacna mreza!  |");
      delay(1500);
      lcd.clear();
      lcd.setCursor(1, 0);
      lcd.print("1. Ping -> loklani");
      lcd.setCursor(1, 1);
      lcd.print("2. Ping -> google");
      lcd.setCursor(1, 2);
      lcd.print("3. Ping -> Voice");
      lcd.setCursor(1, 3);
      lcd.print("4. Ping -> Video");
    }
  }

  //PREVRERJA4!
  if (!buttonState4)
  {
    //NIČ NI PRITISNENO;
  }
  else if (buttonState4 == 1)
  {
    if (Gateway[0] == 10) {
      videoDolg();
      delay(1000);
    }
    else {
      lcd.clear();
      lcd.setCursor(0, 0);
      lcd.print("--------------------");
      lcd.setCursor(0, 3);
      lcd.print("--------------------");
      lcd.setCursor(0, 2);
      lcd.print("|                  |");
      lcd.setCursor(0, 1);
      lcd.print("|  Napacna mreza!  |");
      delay(1500);
      lcd.clear();
      lcd.setCursor(1, 0);
      lcd.print("1. Ping -> loklani");
      lcd.setCursor(1, 1);
      lcd.print("2. Ping -> google");
      lcd.setCursor(1, 2);
      lcd.print("3. Ping -> Voice");
      lcd.setCursor(1, 3);
      lcd.print("4. Ping -> Video");
    }
  }
  else if (buttonState4 == 2)
  {
    if (Gateway[0] == 10) {
      videoKratek();
    }
    else {
      lcd.clear();
      lcd.setCursor(0, 0);
      lcd.print("--------------------");
      lcd.setCursor(0, 3);
      lcd.print("--------------------");
      lcd.setCursor(0, 2);
      lcd.print("|                  |");
      lcd.setCursor(0, 1);
      lcd.print("|  Napacna mreza!  |");
      delay(1500);
      lcd.clear();
      lcd.setCursor(1, 0);
      lcd.print("1. Ping -> loklani");
      lcd.setCursor(1, 1);
      lcd.print("2. Ping -> google");
      lcd.setCursor(1, 2);
      lcd.print("3. Ping -> Voice");
      lcd.setCursor(1, 3);
      lcd.print("4. Ping -> Video");
    }
  }
}
